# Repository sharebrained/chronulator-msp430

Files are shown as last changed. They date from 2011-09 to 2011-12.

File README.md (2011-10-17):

chronulator-msp430
==================

by ShareBrained Technology

The latest version of this repository can be found at:
<https://github.com/sharebrained/chronulator-msp430>

Description
===========

An analog panel meter clock implementation based on the
Texas Instruments MSP430 microcontroller.

Time is displayed via two analog meters, one for hours
and one for minutes. The microcontroller keeps time via
a 32.768kHz crystal, and controls the meter needles
using pulse-width modulation of current sources.

The current sources are adjustable by variable
resistors, and the time is set by momentary buttons.

Documentation
=============

See http://www.sharebrained.com/chronulator/archive/
for hardware documentation.

Requirements
============

Software
--------

* TI Code Composer Studio (to program the Chronulator
  firmware)
* EAGLE 5.x (to edit the schematic or circuit board)

Hardware
--------

* A Chronulator or Chronulator-compatible device based
  on the TI MSP430 (ShareBrained Chronulators with
  circuit board version 1.3 or earlier).
* A TI ez430 programmer.

Contact
=======

ShareBrained Technology, Inc.
<http://www.sharebrained.com/>

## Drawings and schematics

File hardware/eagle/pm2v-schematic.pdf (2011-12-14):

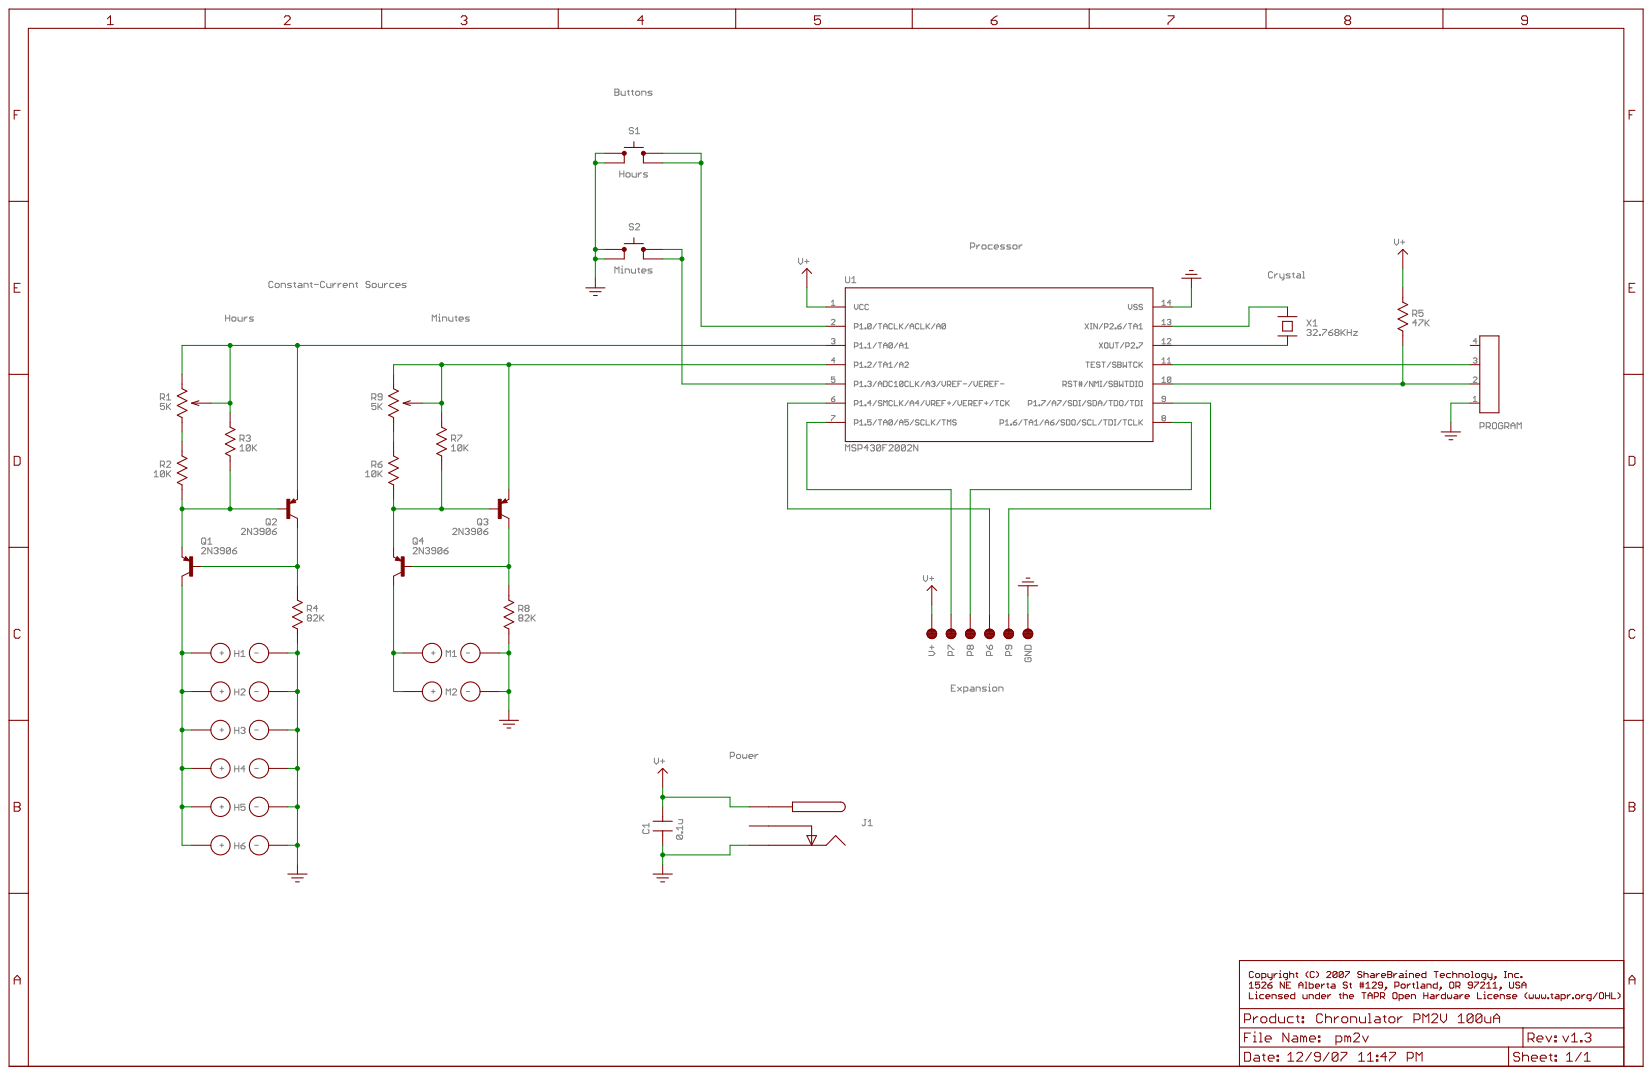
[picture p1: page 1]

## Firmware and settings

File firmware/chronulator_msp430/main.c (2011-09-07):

/*
 * Copyright (C) 2007 ShareBrained Technology, Inc.
 * 
 * This file is part of the Chronulator PM2V software package.
 * 
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
 * The Chronulator PM2V software package is distributed in the
 * hope that it will be useful, but WITHOUT ANY WARRANTY;
 * without even the implied warranty of MERCHANTABILITY or
 * FITNESS FOR A PARTICULAR PURPOSE.  See the GNU General Public
 * License for more details.
 * 
 * You should have received a copy of the GNU General Public
 * License along with this program.  If not, see
 * <http://www.gnu.org/licenses/>.
 */
 
#include "msp430x20x2.h"

__interrupt void Watchdog_ISR(void);

typedef enum meter_mode
{
	METER_MODE_SHOW_TIME = 0,
	METER_MODE_CALIBRATE_ZERO_SCALE = 1,
	METER_MODE_CALIBRATE_FULL_SCALE = 2
} meter_mode_t;

static meter_mode_t meter_mode = METER_MODE_SHOW_TIME;

static const unsigned char debounce_wait = 16;

static unsigned char debounce_counter_s1 = 0;
static unsigned char debounce_counter_s2 = 0;

static unsigned char s1_active = 0;
static unsigned char s2_active = 0;

unsigned char timer_count_h = 0;
unsigned char timer_count_m = 0;

// Variables to store the current time, along with defaults
// for when the device is first powered up.
static unsigned char hour = 6;
static unsigned char minute = 30;
static unsigned char second = 0;

inline void tick_hour(void)
{
	if( hour < 11 )
	{
		hour++;
	}
	else
	{
		hour = 0;
	}
}

inline void tick_minute(void)
{
	if( minute < 59 )
	{
		minute++;
	}
	else
	{
		minute = 0;
		tick_hour();
	}
}

inline void tick_second(void)
{
	if( second < 59 )
	{
		second++;
	}
	else
	{
		second = 0;
		tick_minute();
	}
}

inline void add_hour(void)
{
	if( hour < 11 )
	{
		hour++;
	}
	else
	{
		hour = 0;
	}
}

inline void subtract_hour(void)
{
	if( hour > 0 )
	{
		hour--;
	}
	else
	{
		hour = 11;
	}
}

inline void add_minute(void)
{
	// Increment the minute. If we're already at or above
	// 59, set it to zero instead.
	if( minute < 59 )
	{
		minute++;
	}
	else
	{
		minute = 0;
	}
}

inline void subtract_minute(void)
{
	if( minute > 0 )
	{
		minute--;
	}
	else
	{
		minute = 59;
	}
}

void show_time()
{
	// We're in time display mode, so compute the timer values.
	// Because of the trickery described above, we're computing
	// the *off* time here, not the on-time. That's why we're
	// subtracting from 64 -- there's 64 timer counts (32.768KHz)
	// for each interrupt.
	timer_count_m = 64 - minute;
	timer_count_h = 64 - (hour * 5);
}

void set_mode_show_time()
{
	meter_mode = METER_MODE_SHOW_TIME;
	show_time();
}

void set_mode_calibrate_zero_scale()
{
	meter_mode = METER_MODE_CALIBRATE_ZERO_SCALE;
	timer_count_m = 64 - 0;
	timer_count_h = 64 - 0;
}

void set_mode_calibrate_full_scale()
{
	meter_mode = METER_MODE_CALIBRATE_FULL_SCALE;
	timer_count_m = 64 - 60;
	timer_count_h = 64 - 60;
}

inline void s1_pressed(void)
{
	switch( meter_mode )
	{
	case METER_MODE_SHOW_TIME:
		if( s2_active )
		{
			// Undo minute increment. We wound up incrementing
			// it on the way in to calibration mode, before the
			// second button was held down.
			subtract_minute();
			set_mode_calibrate_zero_scale();
		}
		else
		{
			add_hour();
			show_time();
		}
		break;
		
	case METER_MODE_CALIBRATE_ZERO_SCALE:
		if( s2_active ) set_mode_calibrate_full_scale();
		break;
		
	case METER_MODE_CALIBRATE_FULL_SCALE:
		if( s2_active ) set_mode_show_time();
		break;
		
	default:
		break;
	}
}

inline void s1_released(void)
{
}

inline void s2_pressed(void)
{
	switch( meter_mode )
	{
	case METER_MODE_SHOW_TIME:
		if( s1_active )
		{
			// Undo hour increment. We wound up incrementing
			// it on the way in to calibration mode, before the
			// second button was held down.
			subtract_hour();
			set_mode_calibrate_zero_scale();
		}
		else
		{
			add_minute();
			// TODO: It was once true that when you released
			// the minute set button (S2), it would reset the
			// second counter, allowing the user to precisely
			// set the "second hand" of the clock. That doesn't
			// work so well with the advent of a two-button
			// clock...
			//second = 0;
			show_time();
		}
		break;
		
	case METER_MODE_CALIBRATE_ZERO_SCALE:
		if( s1_active ) set_mode_calibrate_full_scale();
		break;
		
	case METER_MODE_CALIBRATE_FULL_SCALE:
		if( s1_active ) set_mode_show_time();
		break;
		
	default:
		break;
	}
}

inline void s2_released(void)
{
}

#define S1_PORT P1IN
#define S1_BIT BIT0

#define S2_PORT P1IN
#define S2_BIT BIT3

inline void debounce_buttons(void)
{
	// Each switch has a debounce counter.
	// The debounce counter causes us to sample S1 a bunch
	// of times before we consider the button to really be
	// pressed. This is important because most switches
	// don't close cleanly when pressed -- they make noise,
	// which can cause multiple counts. That'd make setting
	// the time rather difficult, if every time you pressed
	// a button you couldn't be sure if the clock would
	// increment one hour or three... Or seven, or four...
	
	if( s1_active )
	{
		// Last time, S1 was pressed.
		if( S1_PORT & S1_BIT )
		{
			// Button is released, mark button as inactive.
			s1_active = 0;
			s1_released();
		}
	}
	else
	{
		// Last time, S1 was not pressed.
		if( (S1_PORT & S1_BIT) == 0 )
		{

			// S1 is now pressed. Increment the debounce counter.
			debounce_counter_s1++;
			
			// S1 has been pressed for a while, it must be intentional.
			if( debounce_counter_s1 == debounce_wait )
			{
				s1_active = 1;
				s1_pressed();
			}
		}
		else
		{
			debounce_counter_s1 = 0;
		}
	}

	if( s2_active )
	{
		// If button is released, mark button as inactive.
		if( S2_PORT & S2_BIT )
		{
			s2_active = 0;
			s2_released();
		}
	}
	else
	{
		if( (S2_PORT & S2_BIT) == 0 )
		{
			debounce_counter_s2++;
			if( debounce_counter_s2 == debounce_wait )
			{
				s2_active = 1;
				s2_pressed();
			}
		}
		else
		{
			debounce_counter_s2 = 0;
		}
	}
}
	
WDT_ISR(Watchdog_ISR) __interrupt void Watchdog_ISR(void)
{
	static const unsigned short second_divider = 512;
	static unsigned short second_divider_count = 1;
	
	// A bit of fancy footwork occurs here. We're using a 32.768KHz
	// quartz crystal as our timebase. And while the MSP430 has two
	// PWM counters, a third would be required to get decent meter
	// resolution (60 ticks) while keeping the PWM cycle (refresh
	// rate) fast enough that the needle doesn't jiggle or vibrate.
	
	// What we've done is used the real-time clock interrupt to act
	// as our PWM cycle timer. Inside the interrupt, we force the PWM
	// outputs 0/low/off. Then, we schedule the PWM to go high at a
	// point in the future that will give us the correct on-time when
	// the next RTC interrupt occurs.
	
	// Since this interrupt runs in the PWM off-time, it's important
	// that we setup the PWM immediately and that it takes a
	// consistent amount of time. If the setup takes a long time, we
	// may be late turning the PWM on if PWM duty cycle is high (in
	// other words, the PWM output is 1/high/on most of the time).
	// Or, if the setup code is inconsistent, the meter needles will
	// dance around a bit.
	
	// Once the PWM's on-time is set, we have time to relax and do
	// user-interface and housekeeping stuff. Once that work is done,
	// we exit the interrupt. Upon leaving the interrupt, the MSP430
	// restores its prior power state -- going to sleep to save its
	// batteries.
	
	// Reset timer count.
    TACTL	= TASSEL_1 |	// source: ACLK/VLO
    		  ID_0 |		// divide by: 1 (no-op)
    		  MC_2 |		// mode: continuous
    		  TACLR |		// clear count, divider, direction: yes
    		  0 |			// interrupt: disabled
    		  0;			// interrupt pending: no

	// Force PWM OUT pins low.
	TACCTL0	= CM_0 |		// capture mode: no
			  CCIS_0 |		// capture/compare input: CCI0A (don't care)
			  0 |			// synchronize capture source: asynchronous capture
			  0 |			// capture mode: compare
			  OUTMOD_0 |	// output mode: OUT
			  0 |			// capture/compare interrupt: disabled
			  0 |			// output (mode 0 only): 1
			  0 |			// capture overflow: clear
			  0;			// capture/compare interrupt pending: no
	TACCTL1	= CM_0 |		// capture mode: no
			  CCIS_0 |		// capture/compare input: CCI0A (don't care)
			  0 |			// synchronize capture source: asynchronous capture
			  0 |			// capture mode: compare
			  OUTMOD_0 |	// output mode: OUT
			  0 |			// capture/compare interrupt: disabled
			  0 |			// output (mode 0 only): 1
			  0 |			// capture overflow: clear
			  0;			// capture/compare interrupt pending: no

	// Configure PWM behavior to set OUT high when timer expires.
    TACCTL0 = CM_0 |		// capture mode: no
    		  CCIS_0 |		// capture/compare input: CCI0A (don't care)
    		  0 |			// synchronize capture source: asynchronous capture
    		  0 |			// capture mode: compare
    		  OUTMOD_1 |	// output mode: set (reset on TACLR)
    		  0 |			// capture/compare interrupt: disabled
    		  0 |			// output (mode 0 only): 1
    		  0 |			// capture overflow: clear
    		  0;			// capture/compare interrupt pending: no    
    TACCTL1 = CM_0 |		// capture mode: no
    		  CCIS_0 |		// capture/compare input: CCI1A (don't care)
    		  0 |			// synchronize capture source: asynchronous capture
    		  0 |			// capture mode: compare
    		  OUTMOD_1 |	// output mode: reset (reset on TACLR)
    		  0 |			// capture/compare interrupt: disabled
    		  0 |			// output (mode 0 only): 1
    		  0 |			// capture overflow: clear
    		  0;			// capture/compare interrupt pending: no

	// Set timer durations.
	TACCR1 = timer_count_m;
	TACCR0 = timer_count_h;

	// Update time.
	// Since this interrupt routine is run 512 times a second (by the
	// RTC/watchdog timer), we must count 512 interrupts before
	// incrementing the second.
	second_divider_count--;
	if( second_divider_count == 0 )
	{
		second_divider_count = second_divider;
		tick_second();

		// The seconds, minutes, hours may have changed, so update the
		// timer values (which control the meters). But only update them
		// if we're in "show time" mode.		
		if( meter_mode == METER_MODE_SHOW_TIME )
		{
			show_time();
		}
	}
	
	debounce_buttons();
}

int main(void)
{
	// Configure the watchdog to interrupt every 64 ACLK cycles. ACLK
	// is running at 32.768KHz, so the watchdog interrupt goes off
	// every 1.9 milliseconds, or 512 times a second.
    WDTCTL	= WDT_ADLY_1_9;
	
    P1REN	= 0x09;			// Port 1: bits 0,3 resistors enabled, bits 1,2,4-7 resistors disabled
    P1DIR	= 0xF6;			// Port 1: bits 1,2 are outputs, bits 0,3 are inputs, 4-7 unused (outputs)
    P1SEL	= 0x06;			// Port 1: bits 1,2 are PWM, bits 0,3-7 are GPIO
    P1OUT	= 0x09;			// Port 1: bits 0,3 are pulled up
    P1IES	= 0x00;			// Port 1: interrupt edge selects (don't care)
    P1IE	= 0x00;			// Port 1: no interrupts

    P2REN	= 0x00;			// Port 2: all resistors disabled
    P2DIR	= 0x3F;			// Port 2: bits 0-5 unused (outputs)
    P2SEL	= 0xC0;			// Port 2: bits 6:7 are LFXT1, bits 0:5 are GPIO
    P2OUT	= 0x00;			// Port 2: don't care
    P2IES	= 0x00;			// Port 2: interrupt edge selects (don't care)
    P2IE	= 0x00;			// Port 2: no interrupts

	// There's a trade-off here between running the processor slowly
	// or quickly. Run it slowly, and it requires very little current.
	// But if you have a lot of work for the processor to do, it will
	// get it done very slowly. If you run the processor quickly, it
	// requires more current, but finishes in a fraction of the time.
	// Average power is all we care about.
	
	// How about some hard data?
	// Referring to the MSP430x20x1/2/3 datasheet, figure 3...
	//
	// At 3V,  1MHz:   300uA or   900uW, 900uW/MHz
	//         8MHz: 1,900uA or 5,700uW, 712uW/MHz
	//        12MHz: 2,800uA or 8,400uW, 700uW/MHz
	//
	// Notice that the processor gets more efficient per clock cycle as
	// it runs faster. So we'll save power by running the processor
	// faster. This assumes we can get the job done in the same number
	// of clock cycles, regardless of how fast the processor is running.
	// For this processor, it's true, but for fancier systems (like PCs),
	// running a processor faster introduces memory wait states, hard
	// drive latency, etc., which makes this speed/power analysis far
	// more difficult.

	// Not so fast though -- the processor will not function if running
	// at a high clock speed and very low voltage. Look at the
	// MSP430x20x1/2/3 datasheet to see the limitations.
	
 	BCSCTL1 = XT2OFF |		// XT2OFF: XT2 oscillator: off
			  0 |			// XTS: LFXT1 mode: low frequency
			  0 |			// DIVAx: ACLK divide by: 1
			  13;			// RSELx: Range select: 13: 6 - 9.6MHz
//			  7;			// RSELx: Range select: 7: 1MHz
//			  5;			// RSELx: Range select: 5: 390 - 770KHz
//			  3;			// RSELx: Range select: 3: 200 - 400KHz

	BCSCTL2 = 0 |			// SELMx: MCLK source: DCOCLK
			  0 |			// DIVMx: MCLK divide by: 1
			  0 |			// SELS: SMCLK source: DCOCLK
			  0 |			// DIVSx: SMCLK divide by: 1
			  0;			// DCOR: DCO resistor: internal

    BCSCTL3	= XT2S_0 |		// XT2Sx: XT2 range: 0.4 - 1MHz crystal or resonator
    		  LFXT1S_0 |	// LFXT1Sx: LF clock select: 32768Hz clock
    		  XCAP_3 |		// XCAPx: Crystal load capacitance: ~12.5pF
    		  0 |			// XT2OF: XT2 oscillator fault: none
    		  0;			// LFXT1OF: LFXT1 oscillator fault: none
    
    IE1		|= WDTIE;

	_enable_interrupts();
	
    while(1)						//main loop, never ends...
    {
    	// Go to sleep and wait for an interrupt.
    	LPM3;
	}
}

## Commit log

2011-09-07 Firmware code, schematic, circuit board, design rules for old Chronulator MSP430 design.
    [pm2v.brd, pm2v.sch]
2011-09-07 Changed design in November 2008 to use 100uA meters.
    [pm2v.sch]
2011-12-14 Added Chronulator 1.3 schematic in PDF format for easy browsing of the design.

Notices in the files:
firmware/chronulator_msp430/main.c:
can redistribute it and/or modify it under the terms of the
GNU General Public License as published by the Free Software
